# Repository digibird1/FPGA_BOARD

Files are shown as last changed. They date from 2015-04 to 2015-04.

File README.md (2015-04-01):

# FPGA_BOARD
Eagle design files of a two layer PCB for the ALTERA EP3C5E144 FPGA, including a FTDI USB2.0 controller, 2x 80 MSPS ADC, GPIO, JTAG, configuration FLASH 

https://www.altera.com/en_US/pdfs/literature/hb/cyc3/cyclone3_handbook.pdf

http://www.analog.com/media/en/technical-documentation/data-sheets/AD9057.pdf

http://www.ftdichip.com/Products/ICs/FT232H.htm

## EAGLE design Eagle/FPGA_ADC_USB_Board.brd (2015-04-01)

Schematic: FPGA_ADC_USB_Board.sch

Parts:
C1, C5, C7, C9, C11, C12, C13: 0.1u; C0805
C2, C3: 27p; C0805
C4, C8, C10: 47u; C0805
C6, C15: 0.1; C0805
C14: 10n; C0805
C16, C17, C18, C19, C20, C21, C22, C23, C24, C25, C26, C27, C28, C29, C30, C31, C32, C33, C34, C35, C36, C37, C38, C39, C41, C44, C47, C49, C53, C54, C55, C56, C59, C60, C61: 100n; C0805
C40, C42, C43, C45, C46, C48, C52: 10u; C0805
C50, C51, C57, C58: 100nF; C0805
C62: 1u; C0805
CONFIG_FLASH: EPCS-FALSH; SO08
D1, D2: BAV99; SOT23
D3, D4, D5: PMEG2010AEH; SOD123
EXT_5V: PINHD-1X2; 1X02
IC1: EP3C5E144-V2; EQFP144
IC2: 74LVC1G07DBV; SOT23-5
JTAG: PINHD-2X5; 2X05
L1, L2: 600R/0.5A; R0805
L3, L4, L5, L6, L7: MH2029-300Y; R0805
LED1: Yellow; R0805
LED2: Green; R0805
LED_1, LED_2, LED_3, LED_4: LED_ELED_0805; R0805
LS: 3.3V; SOT223
OSCILLATOR50_MHZ: 636L3I050M00000; OSZI_5X3.2
POWER_SELECT: PINHD-1X3; 1X03
Q1: 12MHz; QS
R1: 12k/1%; M0805
R2, R6, R7, R8: 10k; M0805
R3, R4: 0; M0805
R5: 2k; M0805
R9, R10: 470; M0805
R11: 27; M0805
R12: 24.9; R0805
R13, R14, R15, R17, R18: 10k; R0805
R16: 1k; R0805
R19, R30: 50Ohm; R0805
R20, R21, R22, R23, R24, R25: 0; R0805
R26, R27, R28, R29: 330; R0805
R31: 100k; R0805
R33: 120; R0805
S1: 10-XX; B3F-10XX
U$1: FT232H; LQFP48
U$2, U$6: AD9057; SSOP20
U$3: 93LC56; DIL-08
U$4: 2.5V; SOT223
U$5: 1.2V; SOT223
U$7: FPGA_GPIO_DE0; 2X20
U$8: NET_TIE; NET-TIE
X1: PN61729-S
X2, X3: BU-SMA-V

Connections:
1.2V: C16.1, C17.1, C18.1, C19.1, C20.1, C21.1, C22.1, C23.1, C36.1, C37.1, C48.1, IC1.5 (VCCINT), IC1.29 (VCCINT), IC1.37 (VCCD_PLL), IC1.45 (VCCINT), IC1.61 (VCCINT), IC1.78 (VCCINT), IC1.102 (VCCINT), IC1.109 (VCCD_PLL), IC1.116 (VCCINT), IC1.134 (VCCINT), U$5.2 (OUT), U$5.4 (OUT)
2.5V: C38.1, C39.1, C45.1, IC1.35 (VCCA), IC1.107 (VCCA), JTAG.4, R17.2, R18.2, R20.2, R22.2, R24.2, U$4.2 (OUT), U$4.4 (OUT)
3.3V: C4.1, C5.1, C11.1, C12.1, C13.1, C15.1, C24.1, C25.1, C26.1, C27.1, C28.1, C29.1, C30.1, C31.1, C32.1, C33.1, C34.1, C35.1, C42.1, C54.1, C59.1, CONFIG_FLASH.3 (VCC), CONFIG_FLASH.7 (VCC1), CONFIG_FLASH.8 (VCC2), D1.2 (C2), D2.2 (C2), IC1.17 (VCCIO), IC1.26 (VCCIO), IC1.40 (VCCIO), IC1.47 (VCCIO), IC1.56 (VCCIO), IC1.62 (VCCIO), IC1.81 (VCCIO), IC1.93 (VCCIO), IC1.117 (VCCIO), IC1.122 (VCCIO), IC1.130 (VCCIO), IC1.139 (VCCIO), IC2.5 (VCC), L1.1, L2.1, L6.1, LS.2 (OUT), LS.4 (OUT), R2.2, R6.2, R7.2, R8.2, R9.2, R10.2, R13.2, R14.2, R15.2, R31.2, U$1.12 (VCCIO), U$1.24 (VCCIO2), U$1.39 (VCCD), U$1.40 (VREGIN), U$1.46 (VCCIO3), U$2.15 (V_DD), U$3.8 (VCC), U$6.15 (V_DD), U$7.29 (3.3V)
5V: L3.1, L4.1, L5.1, L7.1, POWER_SELECT.2
5V_ANALOG: C52.1, C53.1, C55.1, C56.1, C60.1, C61.1, L7.2, U$2.5 (V_D1), U$2.8 (V_D2), U$6.5 (V_D1), U$6.8 (V_D2)
5V_EXT: D3.1 (A), POWER_SELECT.1
5V_USB: D5.2 (C), U$7.11 (5V), X1.1
ACBUS0: IC1.50 (IO50), U$1.21 (ACBUS0)
ACBUS1: IC1.44 (IO44), U$1.25 (ACBUS1)
ACBUS2: IC1.43 (IO43), U$1.26 (ACBUS2)
ACBUS3: IC1.38 (IO38), U$1.27 (ACBUS3)
ACBUS4: IC1.34 (IO34), R11.2
ACBUS6: IC1.33 (IO33), U$1.30 (ACBUS6)
ACBUS7: IC1.32 (IO32), U$1.31 (ACBUS7)
ACBUS8: IC1.31 (IO31), LED1.2 (C), U$1.32 (ACBUS8)
ACBUS9: IC1.30 (IO30), LED2.2 (C), U$1.33 (ACBUS9)
ADBUS0: IC1.65 (IO65), U$1.13 (ADBUS0)
ADBUS1: IC1.64 (IO64), U$1.14 (ADBUS1)
ADBUS2: IC1.60 (IO60), U$1.15 (ADBUS2)
ADBUS3: IC1.59 (IO59), U$1.16 (ADBUS3)
ADBUS4: IC1.54 (IO54), U$1.17 (ADBUS4)
ADBUS5: IC1.53 (IO53), U$1.18 (ADBUS5)
ADBUS6: IC1.52 (IO52), U$1.19 (ADBUS6)
ADBUS7: IC1.51 (IO51), U$1.20 (ADBUS7)
ADC1_CLK: IC1.113 (IO113), U$6.10 (ENCODE)
ADC1_D0: IC1.114 (IO114), U$6.20 (D0)
ADC1_D1: IC1.115 (IO115), U$6.19 (D1)
ADC1_D2: IC1.119 (IO119), U$6.18 (D2)
ADC1_D3: IC1.120 (IO120), U$6.17 (D3)
ADC1_D4: IC1.125 (IO125), U$6.14 (D4)
ADC1_D5: IC1.126 (IO126), U$6.13 (D5)
ADC1_D6: IC1.127 (IO127), U$6.12 (D6)
ADC1_D7: IC1.128 (IO128), U$6.11 (D7)
ADC2_CLK: IC1.112 (IO112), U$2.10 (ENCODE)
ADC2_D0: IC1.98 (IO98), U$2.20 (D0)
ADC2_D1: IC1.99 (IO99), U$2.19 (D1)
ADC2_D2: IC1.100 (IO100), U$2.18 (D2)
ADC2_D3: IC1.101 (IO101), U$2.17 (D3)
ADC2_D4: IC1.103 (IO103), U$2.14 (D4)
ADC2_D5: IC1.104 (IO104), U$2.13 (D5)
ADC2_D6: IC1.105 (IO105), U$2.12 (D6)
ADC2_D7: IC1.106 (IO106), U$2.11 (D7)
ADC_GND: C50.2, C55.2, C56.2, C57.2, C60.2, C61.2, R19.2, R30.2, U$2.4 (GND), U$2.9 (GND1), U$6.4 (GND), U$6.9 (GND1), U$8.NET1, X2.2, X2.3 (2), X2.4 (2), X2.5 (2), X3.2, X3.3 (2), X3.4 (2), X3.5 (2)
ASDI: CONFIG_FLASH.5 (ASDI), IC1.6 (IO6)
DATA: IC1.13 (IO13), R12.1
DCLK: CONFIG_FLASH.6 (DCLK), IC1.12 (DCLK)
FPGA_CLK: IC1.91 (CLK4), OSCILLATOR50_MHZ.3 (OUT)
GND: C1.2, C2.2, C3.2, C4.2, C5.2, C6.2, C7.2, C8.2, C9.2, C10.2, C11.2, C12.2, C13.2, C14.2, C15.2, C16.2, C17.2, C18.2, C19.2, C20.2, C21.2, C22.2, C23.2, C24.2, C25.2, C26.2, C27.2, C28.2, C29.2, C30.2, C31.2, C32.2, C33.2, C34.2, C35.2, C36.2, C37.2, C38.2, C39.2, C40.2, C41.2, C42.2, C43.2, C44.2, C45.2, C46.2, C47.2, C48.2, C49.2, C52.2, C53.2, C54.2, C59.2, C62.2, CONFIG_FLASH.4 (GND), D1.1 (A1), D2.1 (A1), D4.2 (C), IC1.19 (GND), IC1.21 (NCE), IC1.27 (GND), IC1.36 (GNDA), IC1.41 (GND), IC1.48 (GND), IC1.57 (GND), IC1.63 (GND), IC1.82 (GND), IC1.95 (GND), IC1.108 (GNDA), IC1.118 (GND), IC1.123 (GND), IC1.131 (GND), IC1.140 (GND), IC1.E (CENTER_GND_PLANE), IC2.3 (GND), JTAG.2, JTAG.10, LED_1.2 (C), LED_2.2 (C), LED_3.2 (C), LED_4.2 (C), LS.1 (GND), OSCILLATOR50_MHZ.2 (GND), R1.1, R16.2, R21.1, R23.1, R25.1, S1.3, S1.4 (P1), U$1.4 (AGND1), U$1.9 (AGND2), U$1.10 (GND1), U$1.11 (GND2), U$1.22 (GND3), U$1.23 (GND4), U$1.35 (GND5), U$1.36 (GND6), U$1.41 (AGND3), U$1.42 (TEST), U$1.47 (GND7), U$1.48 (GND8), U$2.1 (PWRDN), U$2.16 (GND2), U$3.5 (GND), U$4.1 (GND), U$5.1 (GND), U$6.1 (PWRDN), U$6.16 (GND2), U$7.12 (GND), U$7.30 (GND2), U$8.NET2, X1.4
GPIO1_CLKIN0: IC1.88 (CLK7), U$7.1 (CLKIN0)
GPIO1_CLKOUT0: IC1.85 (IO85), U$7.19 (CLKOUT0)
GPIO1_CLKOUT1: IC1.87 (IO87), U$7.21 (CLKOUT1)
GPIO1_D0: IC1.66 (IO66), U$7.2 (D0)
GPIO1_D1: IC1.67 (IO67), U$7.4 (D1)
GPIO1_D2: IC1.68 (IO68), U$7.5 (D2)
GPIO1_D3: IC1.69 (IO69), U$7.6 (D3)
GPIO1_D4: IC1.70 (IO70), U$7.7 (D4)
GPIO1_D5: IC1.71 (IO71), U$7.8 (D5)
GPIO1_D6: IC1.72 (IO72), U$7.9 (D6)
GPIO1_D7: IC1.73 (IO73), U$7.10 (D7)
GPIO1_D8: IC1.74 (IO74), U$7.13 (D8)
GPIO1_D9: IC1.75 (IO75), U$7.14 (D9)
GPIO1_D10: IC1.76 (IO76), U$7.15 (D10)
GPIO1_D11: IC1.77 (IO77), U$7.16 (D11)
GPIO1_D12: IC1.79 (IO79), U$7.17 (D12)
GPIO1_D13: IC1.84 (IO84), U$7.18 (D13)
GPIO1_D14: IC1.86 (IO86), U$7.20 (D14)
LED1: IC1.1 (IO1), R26.2
LED2: IC1.2 (IO2), R27.2
LED3: IC1.3 (IO3), R28.2
LED4: IC1.4 (IO4), R29.2
MSEL0: IC1.94 (MSEL0), R20.1, R21.2
MSEL1: IC1.96 (MSEL1), R22.1, R23.2
MSEL2: IC1.97 (MSEL2), R24.1, R25.2
unnamed: C9.1, C10.1, L1.2, U$1.8 (VPLL)
unnamed: CONFIG_FLASH.2 (DATA), R12.2
unnamed: C1.1, U$1.37 (VCCA)
unnamed: R1.2, U$1.5 (REF)
unnamed: C6.1, U$1.38 (VCCCORE)
unnamed: C2.1, Q1.1, U$1.1 (XCSI)
unnamed: C3.1, Q1.2, U$1.2 (XCSO)
unnamed: C14.1, R2.1, U$1.34 (RESET)
unnamed: R4.1, U$1.7 (DP)
unnamed: IC1.9 (NSTATUS), R13.1
unnamed: D1.3 (COM), R3.2, X1.2
unnamed: R3.1, U$1.6 (DM)
unnamed: C7.1, C8.1, L2.2, U$1.3 (VPHY)
unnamed: D2.3 (COM), R4.2, X1.3
unnamed: IC1.14 (NCONFIG), R14.1
unnamed: IC1.92 (CONF_DONE), R15.1
unnamed: C40.1, C41.1, L3.2, LS.3 (IN)
unnamed: C43.1, C44.1, L4.2, U$4.3 (IN)
unnamed: C46.1, C47.1, L5.2, U$5.3 (IN)
unnamed: D3.2 (C), EXT_5V.1
unnamed: D4.1 (A), EXT_5V.2
unnamed: D5.1 (A), POWER_SELECT.3
unnamed: C49.1, L6.2, OSCILLATOR50_MHZ.1 (OE), OSCILLATOR50_MHZ.4 (VCC)
unnamed: C51.2, U$6.6 (BIAS_OUT), U$6.7 (AIN)
unnamed: C50.1, U$6.2 (VREF_OUT), U$6.3 (VREF_IN)
unnamed: C51.1, R19.1, X2.1
unnamed: C58.2, U$2.6 (BIAS_OUT), U$2.7 (AIN)
unnamed: R6.1, U$1.45 (EECS), U$3.1 (CS)
unnamed: R7.1, U$1.44 (EECLK), U$3.2 (CLK)
unnamed: R5.2, U$1.43 (EEDATA), U$3.3 (DI)
unnamed: R5.1, R8.1, U$3.4 (DO)
unnamed: C57.1, U$2.2 (VREF_OUT), U$2.3 (VREF_IN)
unnamed: C58.1, R30.1, X3.1
unnamed: LED_1.1 (A), R26.1
unnamed: LED_2.1 (A), R27.1
unnamed: LED1.1 (A), R9.1
unnamed: LED2.1 (A), R10.1
unnamed: LED_3.1 (A), R28.1
unnamed: R11.1, U$1.28 (ACBUS4)
unnamed: LED_4.1 (A), R29.1
unnamed: IC2.4 (O), R33.1
unnamed: C62.1, IC2.2 (I), R31.1, S1.1 (S), S1.2 (S1)
NCS: CONFIG_FLASH.1 (NCS), IC1.8 (IO8)
PB0: IC1.133 (IO133), R33.2
TCK: IC1.16 (TCK), JTAG.1, R16.1
TDI: IC1.15 (TDI), JTAG.9, R18.1
TDO: IC1.20 (TDO), JTAG.3
TMS: IC1.18 (TMS), JTAG.5, R17.1
USB_CLK: IC1.25 (CLK3), U$1.29 (ACBUS5)

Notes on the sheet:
3.3V
Here should be some esd protection!!!
Pull ACBus4 High if in FIFO Mode
VCCINT
VCCIO
VCCA
VCCD_PLL
Oscillator 636L3I050M00000
Which Pin is the Oszi?
Power-Down Function Select; Logic High for Power-Down Mode (Digital Outputs Go to High Impedance State).
What about memour can be used as a buffer
Put resistor close to flash
Configuration Scheme Connect MSEL 2/1/0 to 0/1/0 where 0 is GND and 1 is VCCA
Add some LEDs
What about BAT double diode
Make sure to connect the ADC and other to the PLL clk out of the FPGA
Connect the 50MHz clock to more pins? The 60MHz clock of the USB interface into a clock pin?
CHeck that we hav a good ground under the FPGA and not just a single connection!
Check that voltage is evenly distributed And ground is evenly connected as well
Place vias in analog GND
Pushbutton
The CLKOUT are not connected to the CLK Network!!!

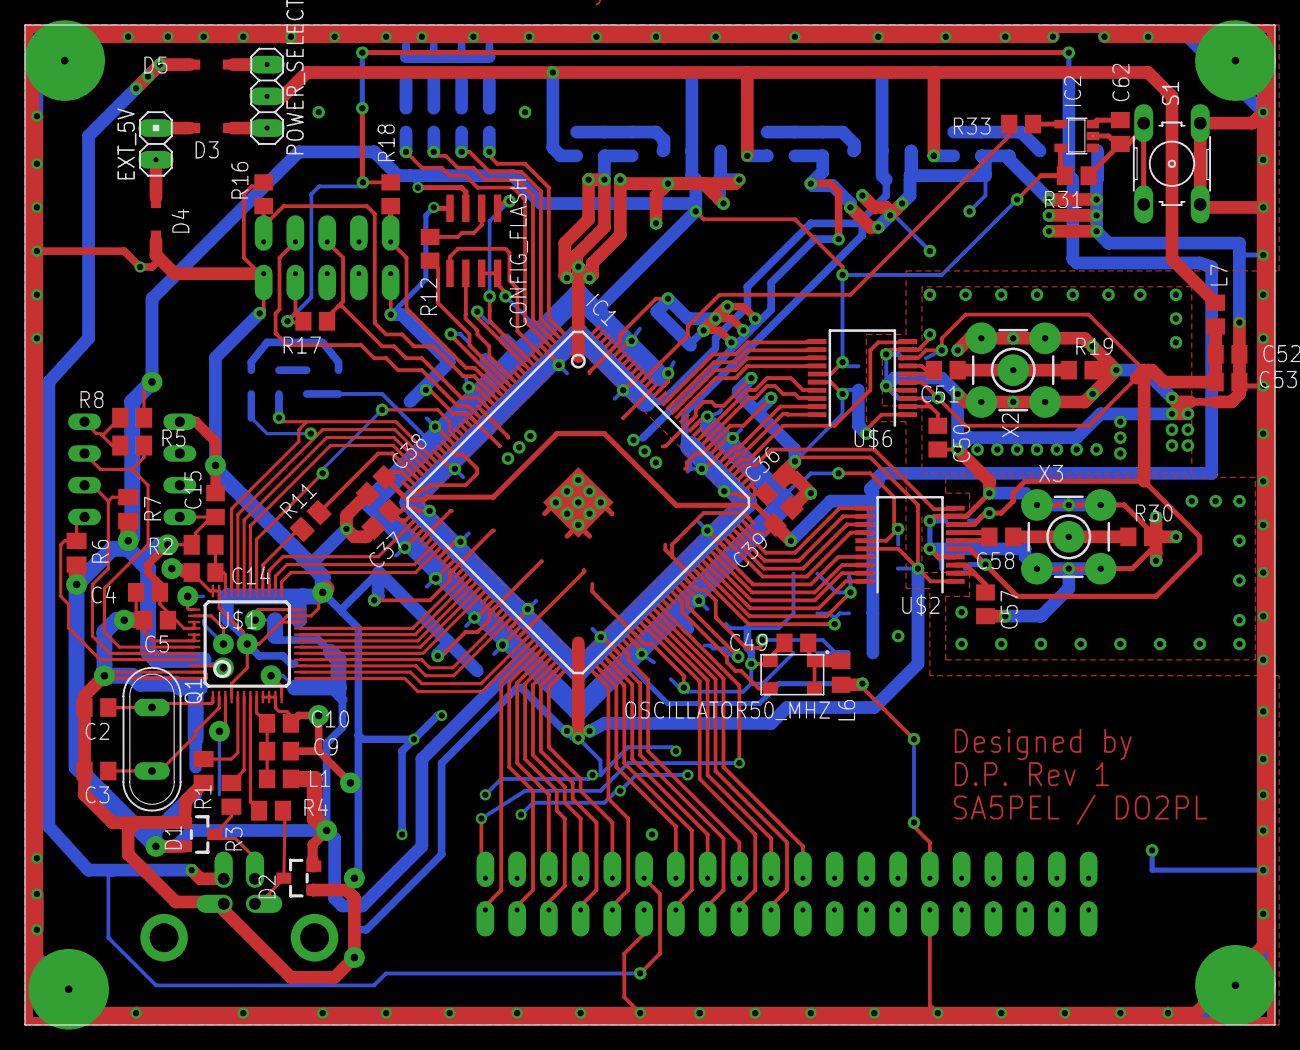
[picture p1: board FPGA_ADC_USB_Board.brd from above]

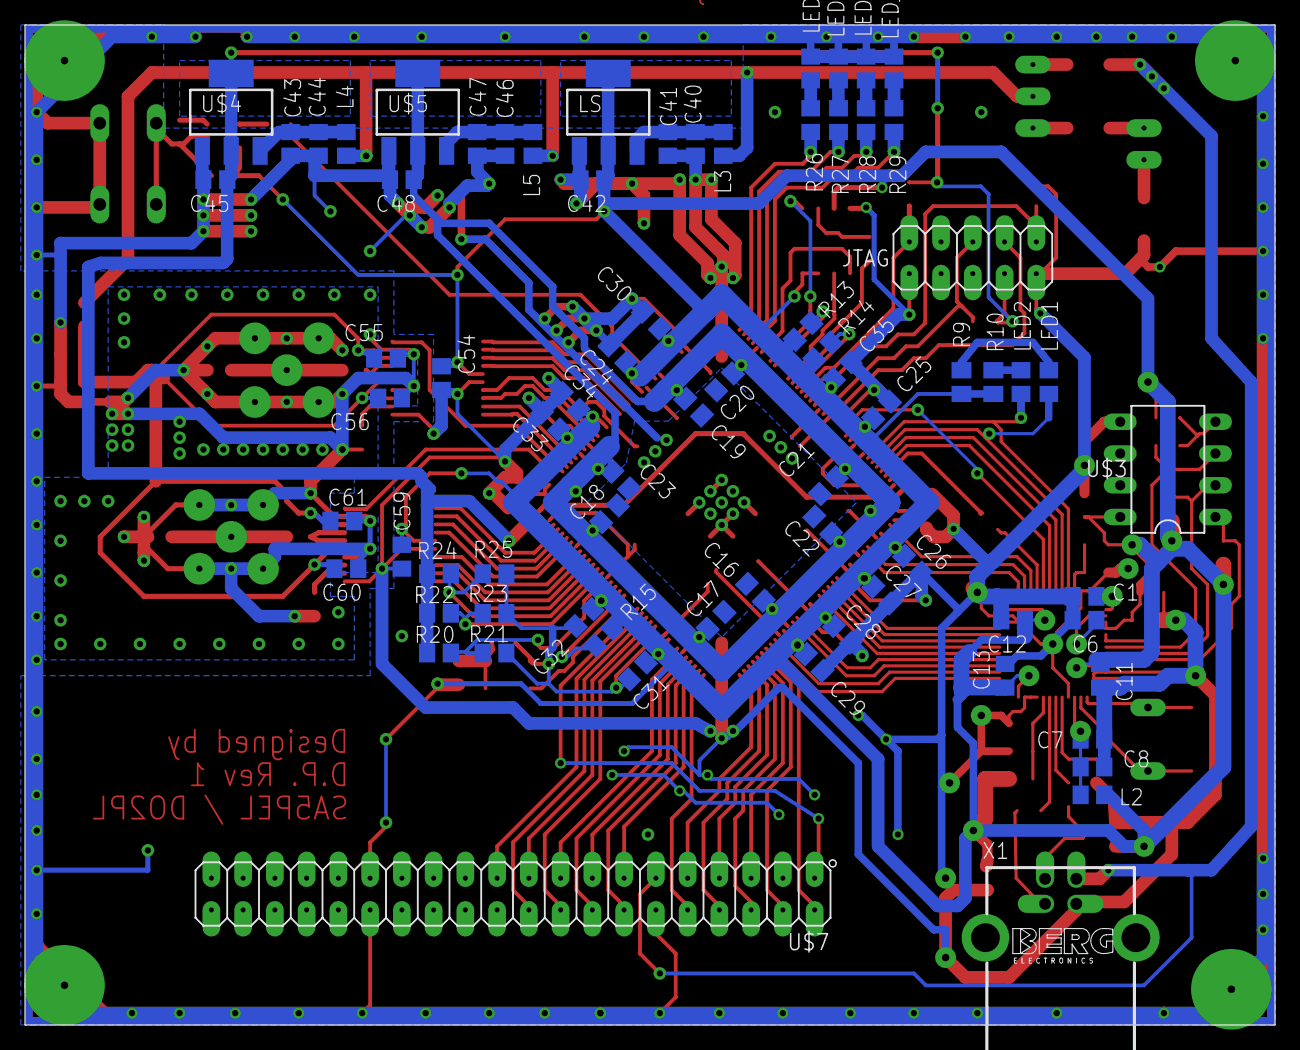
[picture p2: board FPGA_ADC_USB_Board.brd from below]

Board: 2 copper layers, 100.0 x 80.0 mm, 133 parts (74 on the bottom side), 122 nets.

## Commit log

2015-04-01 Eagle PCB files
    [FPGA_ADC_USB_Board.brd, FPGA_ADC_USB_Board.sch]
2015-04-01 Create README.md
    Eagle design files of a two layer PCB for the ALTERA EP3C5E144 FPGA, including a FTDI USB2.0 controller, 2x 80 MSPS ADC, GPIO, JTAG, configuration FLASH
    https://www.altera.com/en_US/pdfs/literature/hb/cyc3/cyclone3_handbook.pdf
    http://www.analog.com/media/en/technical-documentation/data-sheets/AD9057.pdf
    http://www.ftdichip.com/Products/ICs/FT232H.htm
